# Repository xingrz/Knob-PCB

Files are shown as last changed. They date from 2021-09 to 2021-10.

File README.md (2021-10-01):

Knob-PCB
==========

Knob 是一个蓝牙遥控器，基于 [ESP32-C3](https://www.espressif.com/zh-hans/products/socs/esp32-c3) 平台开发。

观看视频: https://www.bilibili.com/video/BV1Nq4y1Z7mp

## 主要元器件

* 主控: 乐鑫 ESP32-C3-MINI-1 (常温版 ESP32-C3FN4)
* 编码器: BOURNS PEC11R-4015F-S0024

## EDA

[KiCad](https://kicad.org/) 5.1.9

## 生产

仓库中的 Gerber、BOM、POS 可直接提交到[嘉立创](https://www.jlc.com/)打样 PCB 和贴片。[BOM 表](KNOB_MAIN_BOM.csv)中包含了嘉立创的原件编号，可自动精确匹配。

## 软件

详见 [Knob-FW](https://github.com/Knob-FW)

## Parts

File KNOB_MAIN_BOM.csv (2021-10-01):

Manufacturer | Comment | Designator | Footprint | Quantity | PartNumber | Source
SAMSUNG 三星 | 10nF | C6 | C_0402_1005Metric | 1 | C15195 | JLC
SAMSUNG 三星 | 1uF/25V | C3 | C_0402_1005Metric | 1 | C52923 | JLC
SAMSUNG 三星 | 100nF/50V | C5 | C_0603_1608Metric | 1 | C14663 | JLC
SAMSUNG 三星 | 10uF/10V | C4 | C_0603_1608Metric | 1 | C19702 | JLC
SAMSUNG 三星 | 10uF/25V | C1 C2 | C_0805_2012Metric | 2 | C15850 | JLC
EVERLIGHT 台湾亿光 | BLUE | D4 D5 | LED_0603_1608Metric | 2 | C72041 | JLC
UNIOHM 台湾厚声 | 0 | R4 | R_0402_1005Metric | 1 | C17168 | JLC
UNIOHM 台湾厚声 | 220 | R6 | R_0402_1005Metric | 1 | C25091 | JLC
UNIOHM 台湾厚声 | 5.1K | R1 R2 | R_0402_1005Metric | 2 | C25905 | JLC
UNIOHM 台湾厚声 | 10K | R3 | R_0402_1005Metric | 1 | C25744 | JLC
UNIOHM 台湾厚声 | 0 | R5 | R_0603_1608Metric | 1 | C21189 | JLC
LRC 乐山无线电 | LESD5Z5.0CT1G | D1 D2 D3 | D_SOD-523 | 3 | C136167 | JLC-EXT
BOURNS | PEC11R-4015F-S0024 | SW1 | BOURNS_PEC11R-4XXXX-SXXXX_SMD | 1 | C143789 | LCSC
HRO 韩荣 | HRO_TYPE-C-31-M-12 | J1 | HRO_TYPE-C-31-M-12 | 1 | C165948 | LCSC
ESPRESSIF 乐鑫 | ESP32-C3-MINI-1 | U2 | ESP32-C3-MINI-1 | 1 | C2838502 | TAOBAO
TI 德州仪器 | LP2992AIM5X-3.3 | U1 | SOT-23-5 | 1 | C111076 | TAOBAO

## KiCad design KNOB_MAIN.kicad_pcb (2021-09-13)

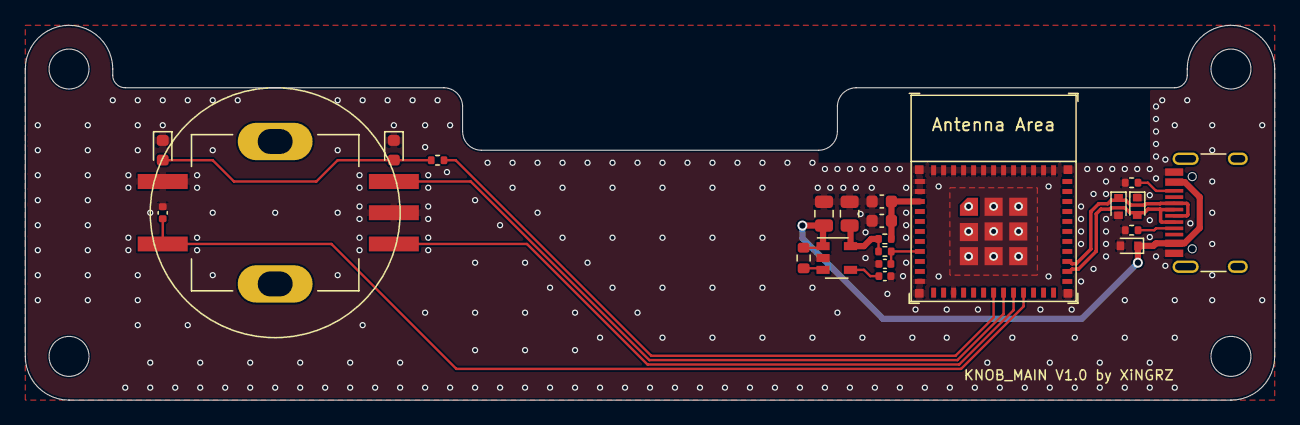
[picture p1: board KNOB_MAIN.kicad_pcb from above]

Board: 2 copper layers, 100.0 x 30.0 mm, 26 parts (0 on the bottom side), 16 nets.

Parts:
C1, C2: 10uF/25V; C_0805_2012Metric
C3: 1uF/25V; C_0402_1005Metric
C4: 10uF/10V; C_0603_1608Metric
C5: 100nF/50V; C_0603_1608Metric
C6: 10nF; C_0402_1005Metric
C7: 100nF; C_0402_1005Metric
D1, D2, D3: LESD5Z5.0CT1G; D_SOD-523
D4, D5: BLUE; LED_0603_1608Metric
H1, H2, H3, H4: Mount; MountingHole_3.2mm_M3
J1: HRO_TYPE-C-31-M-12
R1, R2: 5.1K; R_0402_1005Metric
R3: 10K; R_0402_1005Metric
R4: 0; R_0402_1005Metric
R5: 0; R_0603_1608Metric
R6: 220; R_0402_1005Metric
SW1: PEC11R-4220F-S0024; BOURNS_PEC11R-4XXXX-SXXXX_SMD
U1: LP2992AIM5X-3.3; SOT-23-5
U2: ESP32-C3-MINI-1

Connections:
+3V3: C2.1, R3.1, R4.1, U1.5
+5V: C1.1, D3.1, J1.A4, J1.A9, J1.B4, J1.B9, R5.2, U1.1
/D+: D1.1, J1.A6, J1.B6, U2.27
/D-: D2.2, J1.A7, J1.B7, U2.26
/ENTER: C7.1, SW1.S1, U2.21
/ROTARY_A: SW1.A, U2.20
/ROTARY_B: SW1.B, U2.19
/STATUS: R6.2, U2.18
GND: C1.2, C2.2, C3.2, C4.2, C5.2, C6.2, C7.2, D1.2, D2.1, D3.2, D4.1, D5.1, J1.A1, J1.A12, J1.B1, J1.B12, R1.1, R2.1, SW1.C, SW1.S2, U1.2, U2.1, U2.2, U2.11, U2.14, U2.36
unnamed: C3.1, R3.2, U2.8
unnamed: C4.1, C5.1, R4.2, U2.3
unnamed: C6.1, U1.4
unnamed: D4.2, D5.2, R6.1
unnamed: J1.A5, R1.2
unnamed: J1.B5, R2.2
unnamed: R5.1, U1.3

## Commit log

2021-08-23 Main sch and pcb layout
    [KNOB_MAIN.kicad_pcb, KNOB_MAIN.sch]
2021-08-23 Add front panel
    [KNOB_PANEL.kicad_pcb, KNOB_PANEL.sch]
2021-08-23 Output gerber
    [KNOB_MAIN-Bottom_Cu.gbr, KNOB_MAIN-Bottom_Mask.gbr, KNOB_MAIN-Bottom_Paste.gbr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]
2021-08-23 Change to M3 screws
    [KNOB_MAIN.kicad_pcb, KNOB_MAIN.sch, KNOB_PANEL.kicad_pcb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]
2021-08-23 Update packages
    [KNOB_MAIN.kicad_pcb, KNOB_MAIN.sch]
2021-08-31 Use LP2992AIM5X-3.3 LDO and adjust layout
    [KNOB_MAIN.kicad_pcb, KNOB_MAIN.sch]
2021-09-01 Use 1.6mm board for better strength
    [KNOB_MAIN.kicad_pcb]
2021-09-01 Increase radius of knob hole to 10.4mm
    [KNOB_PANEL.kicad_pcb]
2021-09-01 Add specific custom number on panel
    [KNOB_PANEL-Bottom_Cu.gbr, KNOB_PANEL-Bottom_Mask.gbr, KNOB_PANEL-Bottom_Paste.gbr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]
2021-09-13 Add 100nF debounce capacitor to push pin
    [KNOB_MAIN.kicad_pcb, KNOB_MAIN.sch]
2021-10-01 Correct model number of encoder
    [KNOB_MAIN_BOM.csv]
